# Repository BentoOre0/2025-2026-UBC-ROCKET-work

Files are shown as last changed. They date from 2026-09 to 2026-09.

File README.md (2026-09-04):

# UBC Rocket, 2025/2026

Hands-on rocketry from my first year in engineering at UBC: mechanical design and CAD,
composite manufacturing, avionics integration, and energetic (separation charge) testing.

Two projects live here. One I built with a sub-team, one I built alone in five days.

---

<table>
<tr>
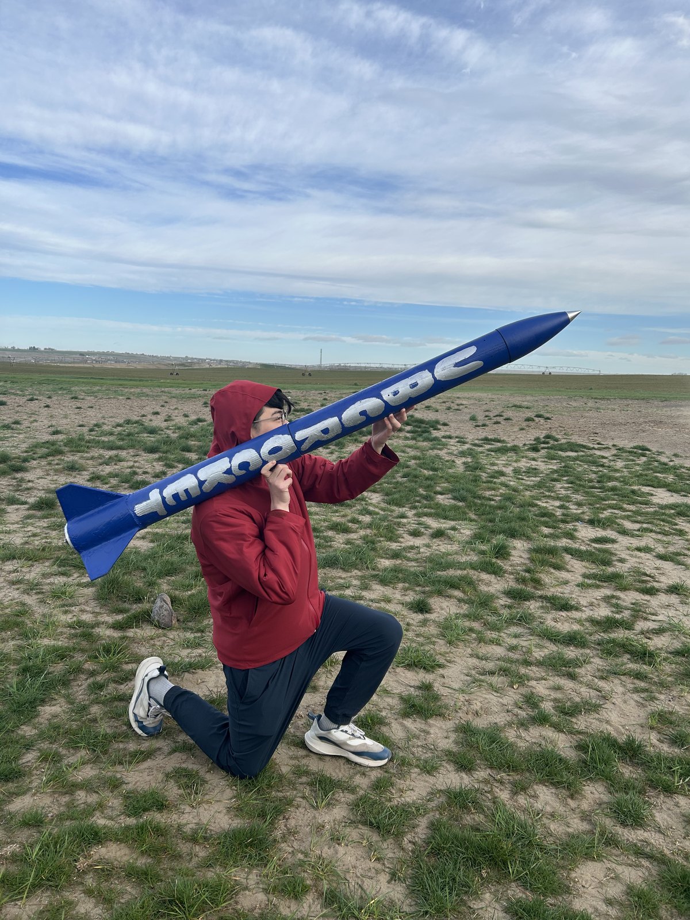
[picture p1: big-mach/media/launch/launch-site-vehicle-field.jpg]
The Big Mach at the launch site
<td width="50%"></td>
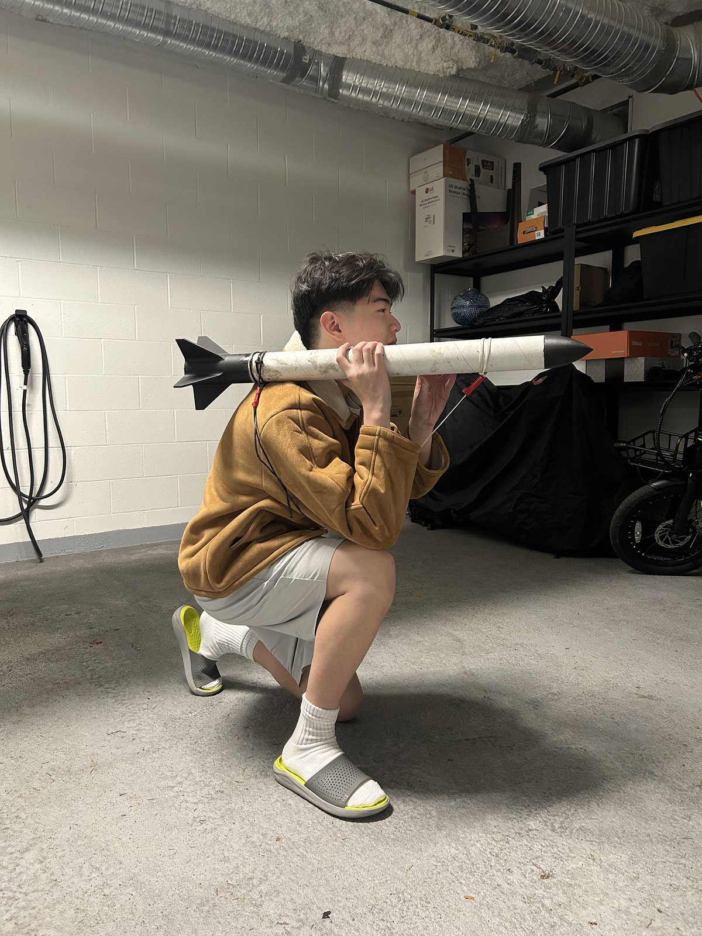
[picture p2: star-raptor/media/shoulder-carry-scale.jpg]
Star Raptor, shoulder carried for scale
<td width="50%"></td>
</tr>
<tr>
<td><h3><a href="big-mach/">The Big Mach</a></h3>
A UBC Rocket test vehicle, built so the team could fly a new reefing parachute system and an in-house avionics stack on hardware it controlled end to end.
<br><br>
<b>My role:</b> full-vehicle CAD and assembly, 3D printing, composite layup, avionics bay integration, separation charge design and ground testing.
<br><br>
<b>Scale:</b> 146 cm long, 10.7 cm diameter, 7.7 kg with motors, L935 motor, simulated Mach 1.03 and 3.06 km apogee.
</td>
<td><h3><a href="star-raptor/">Star Raptor</a></h3>
My own certification rocket, designed and built solo to earn a Canadian Association of Rocketry certification.
<br><br>
<b>My role:</b> everything. Design, CAD, printing, assembly, recovery packing. Built and flight-ready; the certification launch window was scrubbed by weather.
<br><br>
<b>Scale:</b> roughly 1 m, printed nose cone and five-fin can, motor-ejection recovery, no onboard electronics.
<br><br>
<b>CAD:</b> full SolidWorks assembly, section views, and the sliced print files, all in the repo.
</td>
</tr>
</table>

---

## What I actually did

I joined UBC Rocket as a first-year student and was put on the test-rocket sub-team.
The job of that team is to fly other people's new hardware (a reefing parachute system
and a custom avionics stack) on a vehicle we design and build ourselves. So most of my
time went into being the person who takes a requirement from another sub-team and turns
it into geometry, a printed part, a laid-up tube, or a wired-up bay.

Concretely, across the two projects:

| Area | What that meant here |
|---|---|
| **CAD** | Owned and assembled the full `FullAssembly` SolidWorks model of the Big Mach: nose cone sections, body tubes, couplers, bulkheads, centering rings, fin pattern. Modelled Star Raptor from scratch as a six-part SolidWorks assembly, then exported and sliced it myself. |
| **Simulation** | OpenRocket models for stability and trajectory, used to size the airframe and check margin before committing to a layup. |
| **Manufacturing** | 3D printing (including a PA6GF glass-filled-nylon nose cone, glass fill rather than carbon so the avionics' radio signal passes through it), fiberglass wet layups, composite fin work, paint and finishing. |
| **Avionics integration** | Physically fitting the flight computer stack, battery and charge wiring into the bay, and keeping it serviceable by the sub-team that owned it. |
| **Energetics and testing** | Sizing and massing black powder separation charges, wiring e-matches, and firing them over a remote link. |

The avionics bay component (`EDR_AVBAY_DESIGN`) came from the avionics sub-team. The
rest of the assembly and all the mating is mine. Where a claim rests on memory rather than
on something in this repository, I have said so in place rather than dressing it up.

---

## The one that shows the most

The separation charge ground test. Recovery depends on a black powder charge splitting
the airframe at the right moment, and the charge mass is not something you calculate
once and trust. You mass it out, fire it, and watch.

<table>
<tr>
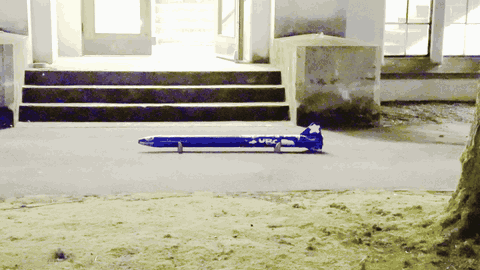
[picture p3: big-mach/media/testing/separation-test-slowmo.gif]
Separation test, slow motion
<td width="50%"></td>
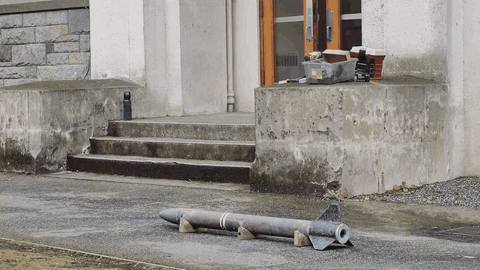
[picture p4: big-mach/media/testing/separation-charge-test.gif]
Separation charge ground test
<td width="50%"></td>
</tr>
<tr>
<td><em>Painted vehicle, filmed at 120fps and slowed roughly 3x. The sections part and stay tethered by the shock cord.</em></td>
<td><em>An earlier test on the bare airframe, real time.</em></td>
</tr>
</table>

The charge mass was found by **binary search**: bracket at 1 g and 2 g, halve the interval,
converge in three to four tests, then repeat at the winning charge to prove it was not
luck. Full detail in the
[Big Mach testing section](big-mach/README.md#separation-charge-testing).

---

## Navigation

| | |
|---|---|
| **[The Big Mach](big-mach/README.md)** | Full engineering case study: design, manufacturing, avionics, testing, launch |
| **[Star Raptor](star-raptor/README.md)** | Solo five-day build, and the scoping decisions that made it possible |
| **[Design media](big-mach/media/design/)** | OpenRocket and SolidWorks screenshots |
| **[Build media](big-mach/media/build/)** | Composite layup, printed parts, avionics bay, finished airframe |
| **[Testing media](big-mach/media/testing/)** | Separation charge ground test, charge mass measurement |
| **[Star Raptor CAD source](star-raptor/cad/)** | SolidWorks parts and assemblies, STEP exports, sliced print files |
| **[Full CAD assembly](https://github.com/BentoOre0/2025-2026-UBC-ROCKET-work/releases/tag/cad-v1)** | The complete SolidWorks assembly, 169 MB, hosted as a release asset |

```text
big-mach/
  README.md
  media/
    design/     OpenRocket + SolidWorks screenshots
    build/      composite layup, printed parts, avionics bay, finished airframe
    testing/    separation charge ground test, charge mass measurement
    launch/     launch site photos and video
star-raptor/
  README.md
  cad/          SolidWorks parts + assemblies, STEP exports, sliced print files
  media/
    cad/        SolidWorks renders and section views
    print/      build plate layouts
    ...         printed fin can, recovery packing, assembled vehicle
```

## The full CAD assembly

The complete SolidWorks assembly is 169 MB, which is too large to sit usefully in a Git
tree, so it is published as a
**[release asset](https://github.com/BentoOre0/2025-2026-UBC-ROCKET-work/releases/tag/cad-v1)**
instead. Start at `FullAssembly.SLDASM`. It needs SolidWorks to open, and the
screenshots in `big-mach/media/design/` are taken from it if you just want to look.

---

*Jeremy Aidan Yu, UBC Engineering*

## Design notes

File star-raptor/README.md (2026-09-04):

# Star Raptor

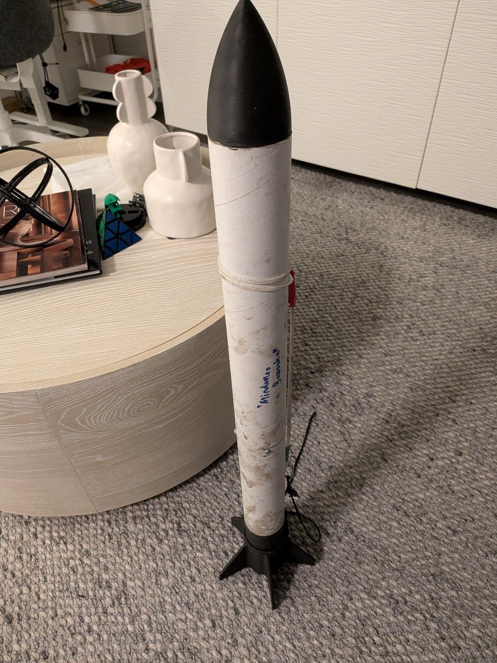
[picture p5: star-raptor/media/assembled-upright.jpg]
Star Raptor assembled


*Star Raptor, assembled and standing on its printed fin can.*

---

## What it is

Star Raptor is **my certification rocket**, a vehicle I designed and built on my own to
earn my Canadian Association of Rocketry certification. It is deliberately much simpler
than [the Big Mach](../big-mach/): no avionics, no separation charges, no composites.

It was also a **five-day build**, constrained by when the certification window fell.

That combination (solo, simple, fast) is the whole point of the project, and it is a
different kind of engineering problem from the Big Mach. On a team vehicle you can
specialise. Here every decision was mine and every decision had to be one I could
actually execute alone, at home, inside a week.

Star Raptor carried on the shoulder for scale

*Star Raptor off the stand. Roughly a metre of airframe: printed nose cone, cardboard
body tube, printed five-fin can, with the kevlar shock cord and its anchor visible at
the shoulder.*

---

## The constraint that shaped it

The design rule I set was: **it has to be buildable at home from printed parts and
hardware-store components, with no electronics.**

That single constraint decides most of the vehicle:

| Decision | Why |
|---|---|
| **Motor-ejection recovery, no flight computer** | The propellant grain has an ejection charge built in. If I let the motor deploy the parachute, I need no altimeter, no battery, no e-matches, no charge wells, and nothing to debug in five days. |
| **3D-printed nose cone and fin can** | The two geometrically fussy parts. Printing them meant I could iterate the fin design without tooling, and a printed fin can guarantees fin alignment far better than I could hand-align individual fins on a tube. |
| **Cardboard body tube** | Adequate for the altitude and velocity involved, and available immediately. Composite work would have cost days I didn't have. |
| **U-bolts, kevlar shock cord, off-the-shelf parachute** | Home Depot and hobby-shop parts. Recovery hardware is the one place not to improvise, and buying it removed a whole category of risk. |

The engineering content here is in the **scoping**, not the sophistication. Choosing a
recovery architecture with no failure modes I'd have to test was the decision that made
a five-day build possible.

---

## Design

I modelled the whole vehicle in SolidWorks as an assembly (`MyRocketAssem`) before
printing anything. For a five-day build that is not ceremony, it is the only way to find
out that two parts do not fit while the fix still costs a re-export instead of a reprint.

<table>
<tr>
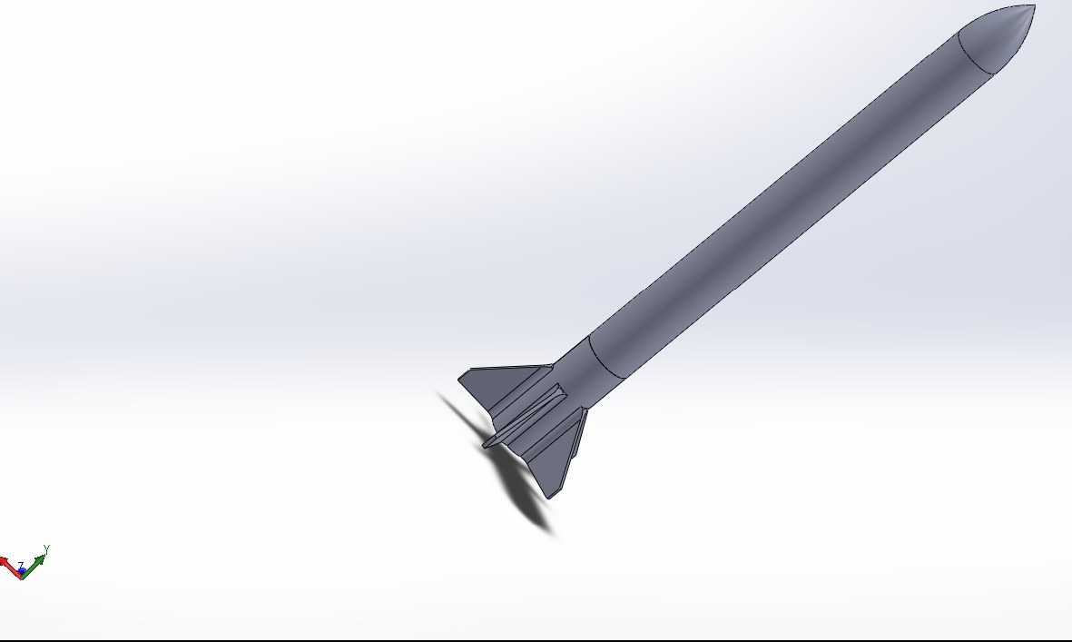
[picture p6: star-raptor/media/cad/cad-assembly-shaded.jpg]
Star Raptor full assembly in SolidWorks
<td width="55%"></td>
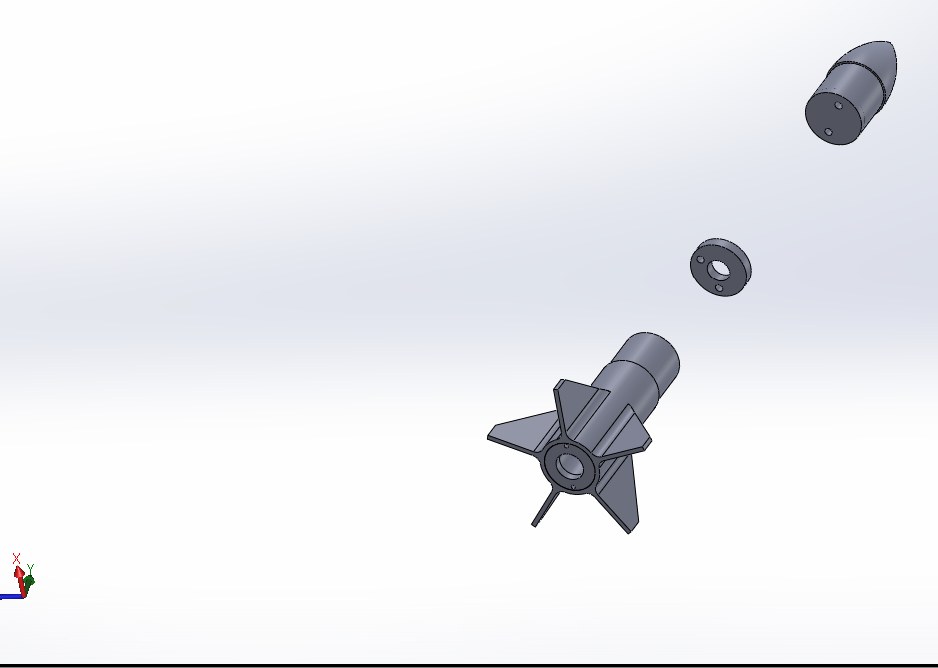
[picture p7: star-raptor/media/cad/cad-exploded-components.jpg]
Exploded view of the printed components
<td width="45%"></td>
</tr>
<tr>
<td><em>The full assembly. Nose cone, body tube, and the printed fin can.</em></td>
<td><em>The same assembly exploded, which is the view that matters for a printed rocket:
nose cone at the top, the ring that anchors the U-bolt below it, and the fin can at the
bottom. These are the parts that have to mate on the first try.</em></td>
</tr>
</table>

The assembly is six parts:

| Part | File |
|---|---|
| Nose cone | `nosecone.SLDPRT` |
| Body tube | `LowerBodyTube.SLDPRT` |
| Fin can, five fins in one piece | `FinCan.SLDPRT` |
| End cap | `endcap.SLDPRT` |
| U-bolt attachment, body tube end | `uboltattatchmentpart.SLDPRT` |
| U-bolt attachment, nose cone end | `Uboltattatchmentpartnosecone.SLDPRT` |

**Five fins was a cosmetic decision.** Three or four fins would have done the job on a
vehicle this size; I went with five because I liked how it looked. The rule I held myself
to was that the styling choice had to survive the stability check rather than drive it,
and it did: extra fin area sits aft of the centre of gravity, so it pushes the centre of
pressure back and the stability margin came out fine. The cost was a little extra drag
and print time. 

### Section views

The section views are what I actually used while designing. On a printed rocket the
walls, the internal tube and the clearances between them are the design, and they are
invisible in a shaded exterior view.

<table>
<tr>
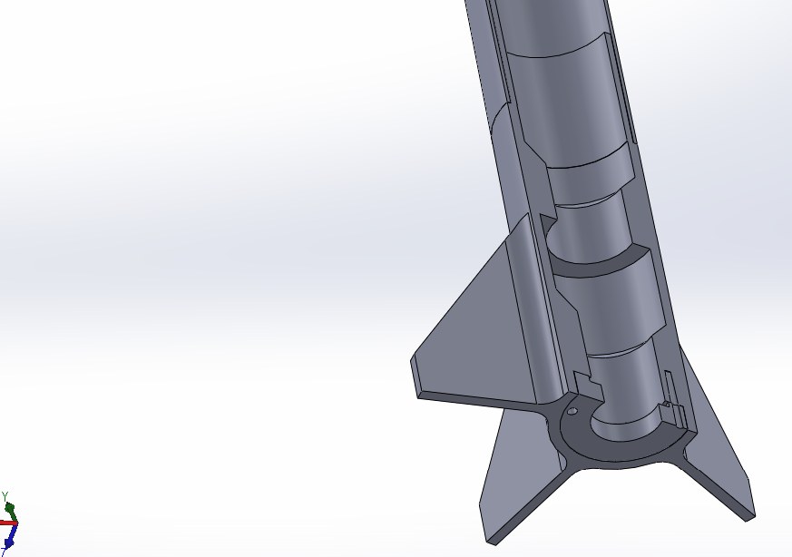
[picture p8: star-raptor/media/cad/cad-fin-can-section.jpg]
Section view through the fin can
<td width="50%"></td>
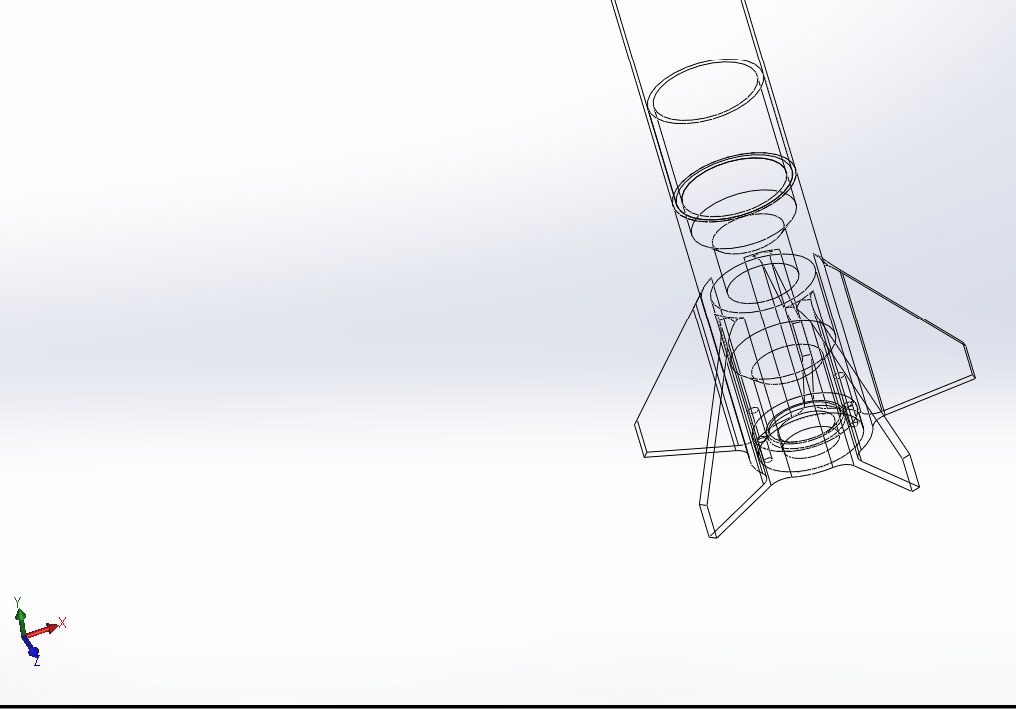
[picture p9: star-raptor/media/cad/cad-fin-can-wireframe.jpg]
Wireframe view of the fin can showing the inner tube
<td width="50%"></td>
</tr>
<tr>
<td colspan="2"><em>Left: a section cut through the aft end, showing the wall thicknesses
and the stepped joint where the fin can meets the body tube. Right: the same region in
wireframe, showing the inner tube running up inside the fin can and the rings that locate
it. Cutting the section is how you catch a wall that is too thin to print or a clearance
that closes up once the tolerances stack.</em></td>
</tr>
</table>

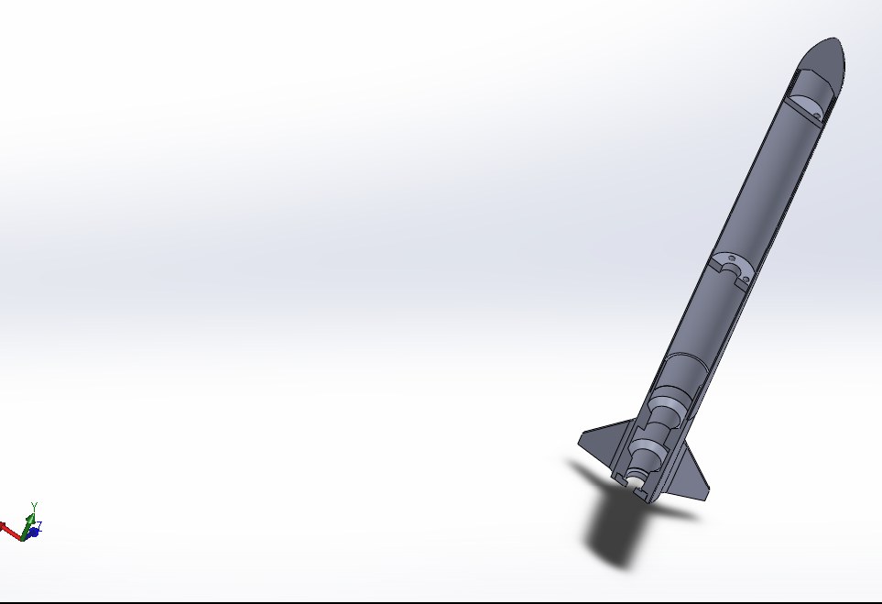
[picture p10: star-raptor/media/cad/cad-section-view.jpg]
Section view of the complete vehicle


*The full vehicle in section, showing how much of the airframe is open volume for the
recovery system.*

**The full CAD source is in [`cad/`](cad/)**: SolidWorks parts and assemblies, the STEP
exports, and the slicer project files. `MyRocketAssemFinal.SLDASM` is the assembly the
built vehicle came from.

---

## Build

### From CAD to printed part

Every printed part went the same route: model it in SolidWorks, export STEP, arrange it
on a build plate, slice, print. The sliced project files are in
[`cad/toprint/`](cad/toprint/) and [`cad/final print top parts/`](cad/final%20print%20top%20parts/),
so the print setup is recoverable rather than just described.

<table>
<tr>
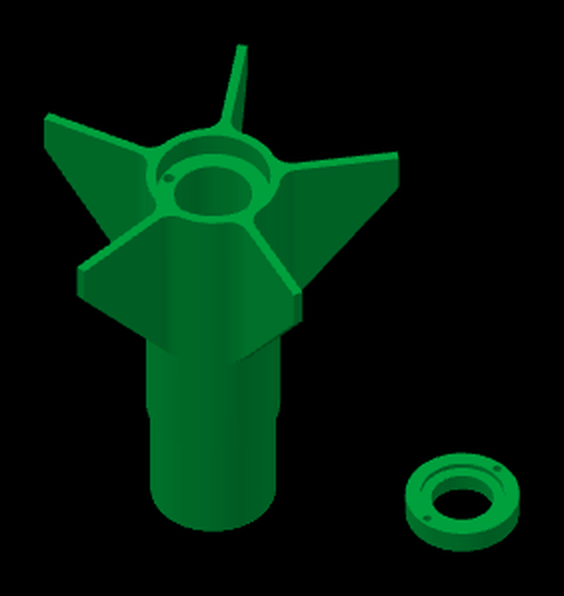
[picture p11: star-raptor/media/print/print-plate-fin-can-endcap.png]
Build plate with the fin can and end cap
<td width="50%"></td>
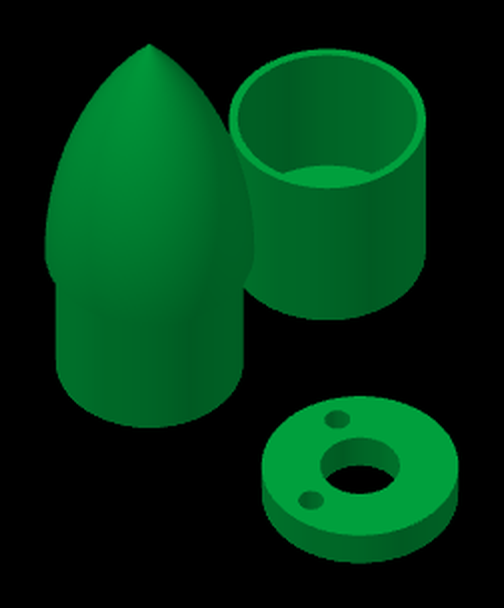
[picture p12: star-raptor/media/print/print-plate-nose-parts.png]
Build plate with the nose cone and U-bolt attachment parts
<td width="50%"></td>
</tr>
<tr>
<td><em>Fin can and end cap on one plate. The fin can prints standing on its aft face, so
the fins are supported by the plate rather than cantilevered in mid-air.</em></td>
<td><em>The upper parts on another plate: nose cone, the body tube U-bolt attachment, and
the nose cone U-bolt attachment.</em></td>
</tr>
</table>

Everything was printed with a **0.6 mm nozzle at 0.30 mm layer height**. That is a coarse
setting, and it was deliberate: a bigger nozzle and thicker layers cut print time hard,
and on structural parts the thicker extrusion is stronger across layer lines than a fine
one. Surface finish was the thing I could afford to give up. Print time was not.

### The physical parts

<table>
<tr>
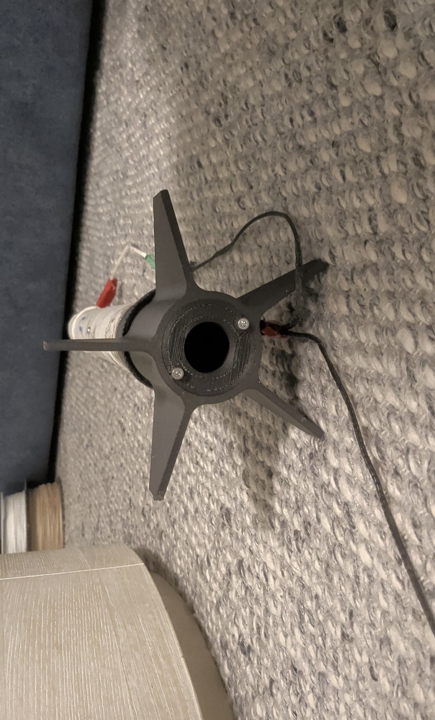
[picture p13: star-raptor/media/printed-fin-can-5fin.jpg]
Printed five-fin can, aft view
<td width="50%"></td>
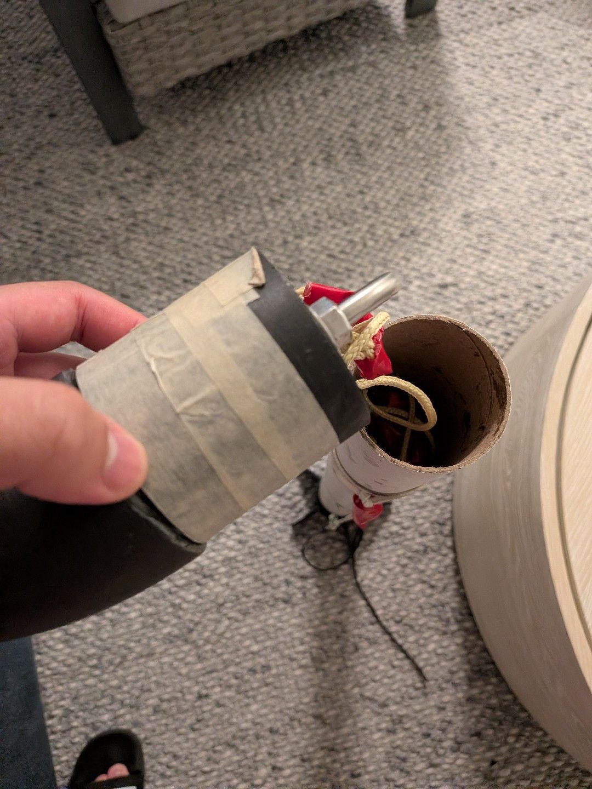
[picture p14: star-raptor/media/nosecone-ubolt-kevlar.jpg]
Nose cone with U-bolt and kevlar shock cord
<td width="50%"></td>
</tr>
<tr>
<td colspan="2"><em>Left: the printed fin can, viewed from the aft end down the motor tube. Printing the fin can as a single part fixes the fin alignment in the model instead of during assembly, and it is what made a five-fin can (a look I chose, not a requirement) no harder to build than a three-fin one. Right: the nose cone's recovery attachment, a through-bolt anchoring the kevlar shock cord. This joint takes the full deployment shock, so it is bolted through the structure rather than glued.</em></td>
</tr>
</table>

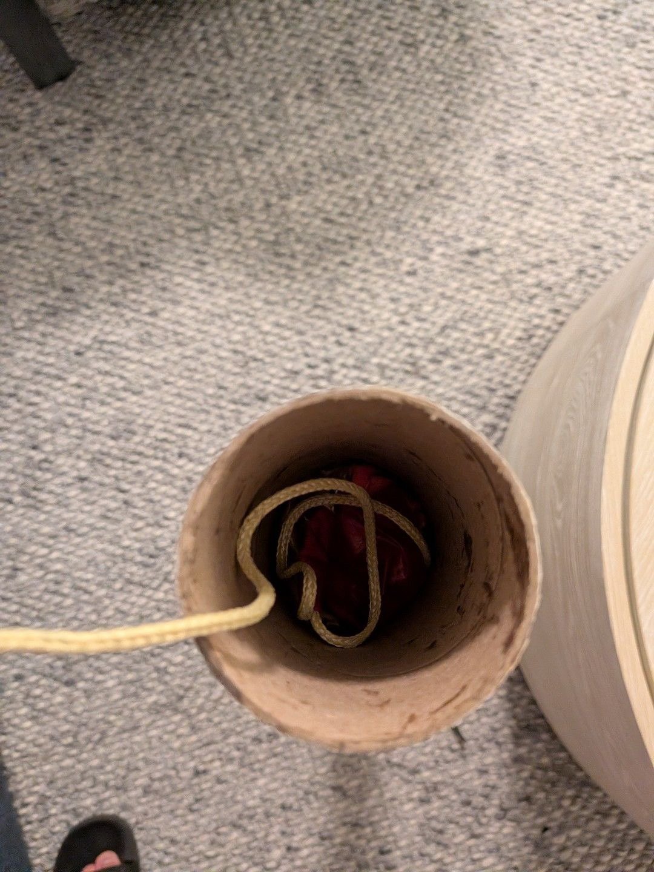
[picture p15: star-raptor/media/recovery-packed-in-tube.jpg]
Recovery packed in the airframe


*Looking down the body tube at the packed recovery system: kevlar shock cord running
down to the anchor, parachute packed above it. The motor's ejection charge pressurises
this volume to push the nose cone and parachute out.*

---

## My role

All of it. Design, CAD, printing, assembly, and recovery packing. No sub-teams, no
inherited hardware. The certification launch window was scrubbed by weather, so the
vehicle in these photos is built and flight-ready but has not flown.

---

## What I took away from it

**Model the whole thing before printing any of it.** The parts that had to mate (fin can
to body tube, nose cone to its U-bolt ring) were the parts most likely to waste a print,
and a full assembly with section views is where you find a wall that is too thin or a
clearance that has closed up. A reprint of the fin can costs hours I did not have. A
re-export costs minutes. Building the assembly first was what kept the five days
realistic.

**print a jig next time.** If I need to drill holes in a circular pattern around a tube 3D print a jig to help with that.

**This was the transition project.** Before this, most of my work was software and
algorithmic. Star Raptor was the first thing I took from a blank SolidWorks assembly to a
finished physical vehicle on my own. Getting an object through that whole loop, including
the parts that are just tedious, is what made the hardware work that followed possible: the Big Mach, and
[the quadruped](https://github.com/BentoOre0/Modded-Nova-SM3).

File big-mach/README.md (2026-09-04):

# The Big Mach

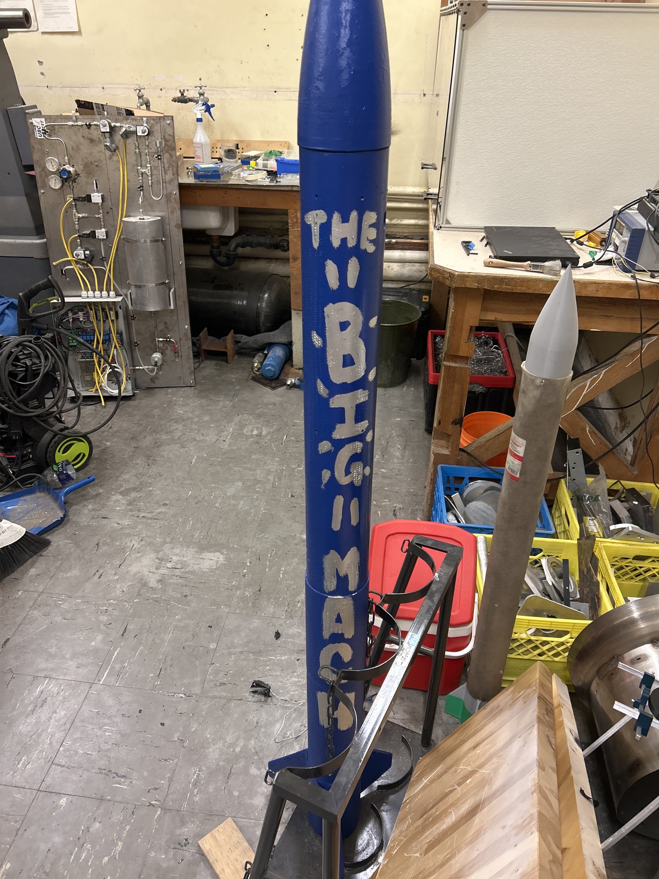
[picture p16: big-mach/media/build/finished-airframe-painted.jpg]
The finished airframe, painted and named


*The Big Mach at the end of the build, in the UBC Rocket workshop. The bare grey
PA6GF nose cone on the right is a spare print of the same part.*

---

## What it is

The Big Mach is a UBC Rocket **test vehicle**. It exists so that two pieces of new
hardware, a reefing parachute recovery system and an in-house avionics stack, could be
flown and characterised on something the team controlled end to end, rather than risking
them on the competition rocket.

That framing drives every design decision on the vehicle. It has to fly high and fast
enough to be a meaningful test, it has to separate reliably to give the recovery system
a chance to work, and the avionics bay has to be accessible enough that another sub-team
can service their own hardware inside it.

From the OpenRocket model (`FINAL_L935_BIG_MACH_with_centering rings.ork`):

| Parameter | Value |
|---|---|
| Length | 146 cm |
| Max diameter | 10.7 cm |
| Mass, no motors | 5176 g |
| Mass, with motors | 7718 g |
| Motor configuration | `3147L935-P` (L-class, 935 N average) |
| Stability margin | 1.5 cal (11%), CG 79.2 cm / CP 95.3 cm |
| Simulated apogee | 3064 m |
| Simulated max velocity | 347 m/s, **Mach 1.028** |
| Simulated max acceleration | 195 m/s² |

The name is not decoration: the simulation puts the vehicle just over Mach 1, which is
what the airframe and fin design had to survive.

<table>
<tr>
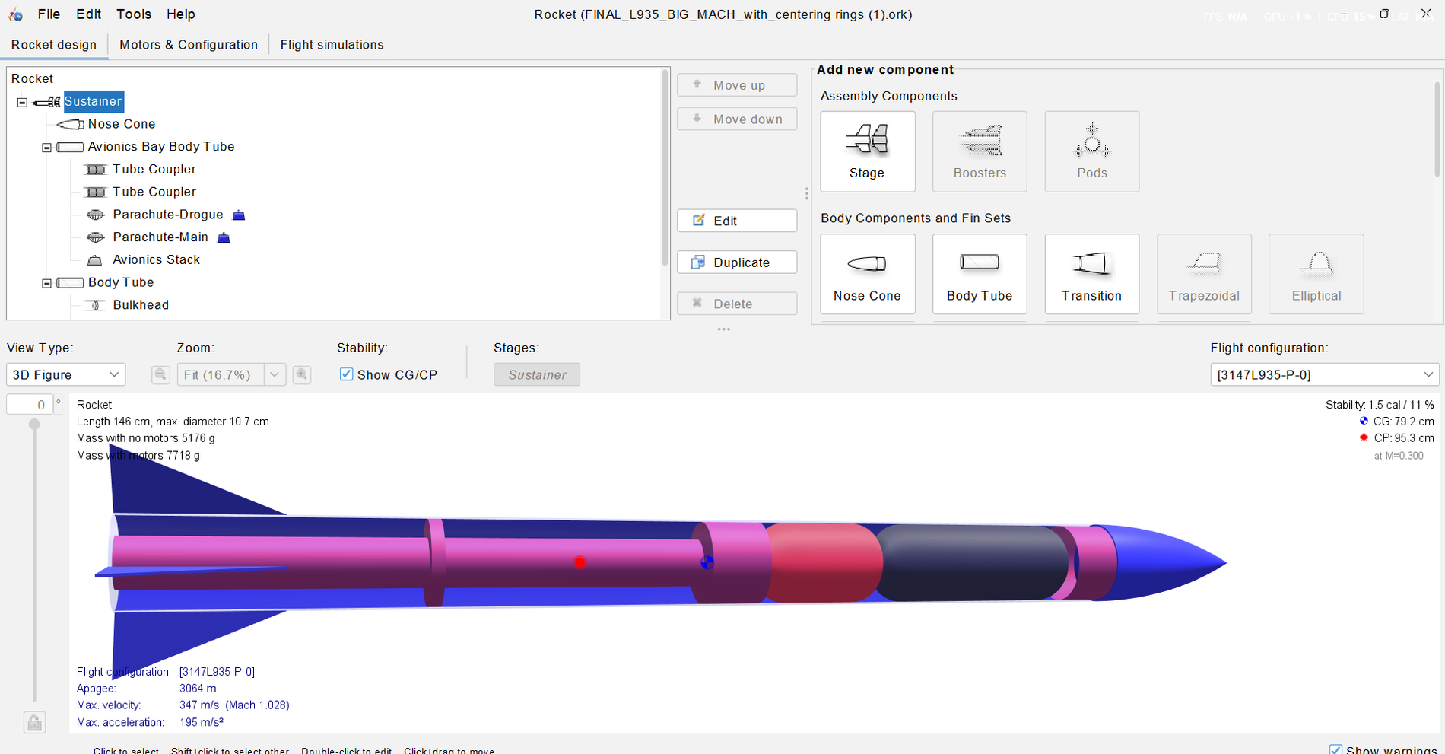
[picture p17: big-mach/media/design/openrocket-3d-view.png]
OpenRocket 3D view
<td width="50%"></td>
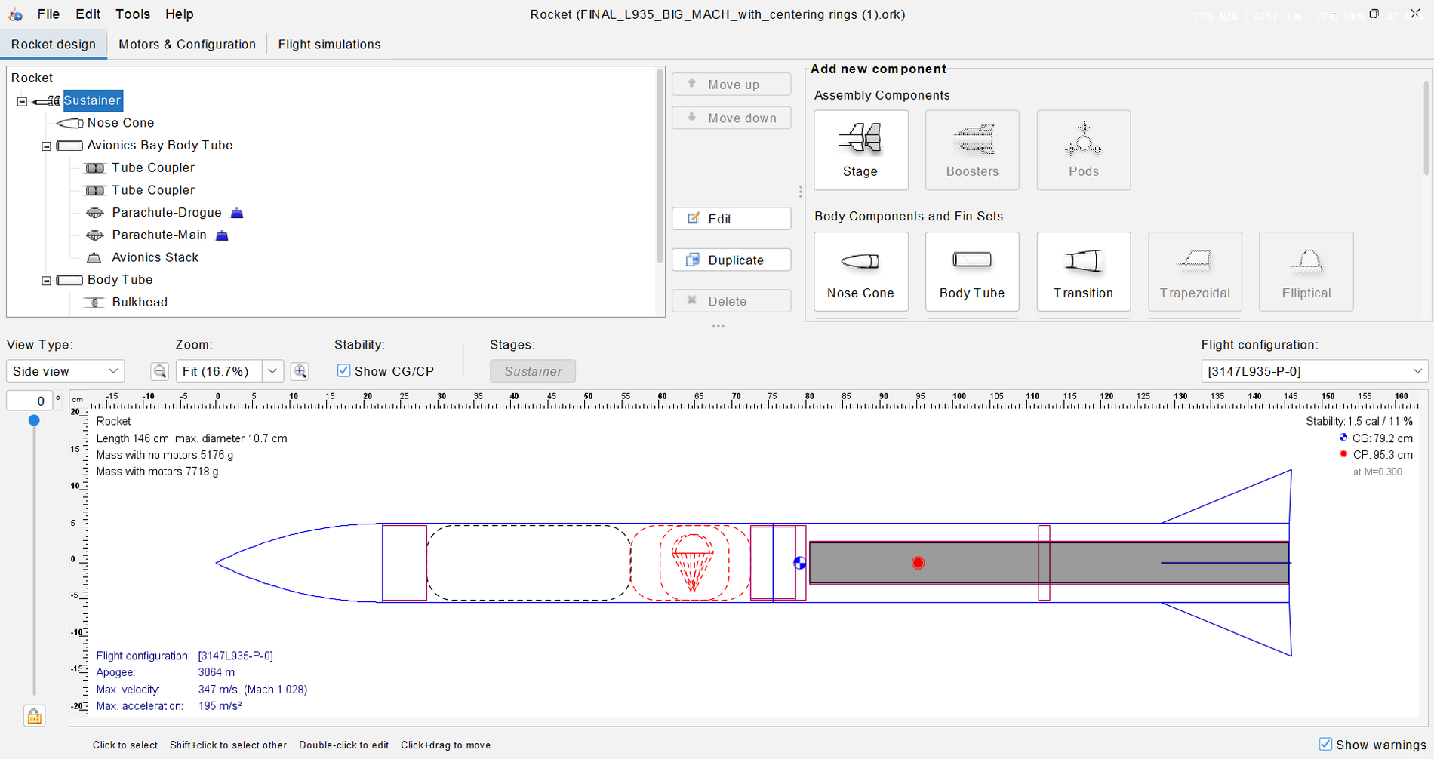
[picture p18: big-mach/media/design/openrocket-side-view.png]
OpenRocket side view with CG and CP marked
<td width="50%"></td>
</tr>
<tr>
<td colspan="2"><em>OpenRocket model. The side view shows the internal stack (nose cone, avionics bay with drogue and main parachutes either side of the avionics stack, coupler, then the motor body tube) and the CG/CP markers used to check the stability margin.</em></td>
</tr>
</table>

---

## My role

I was one of three people on the test-rocket sub-team. The sub-team designed and built
the vehicle; the recovery, avionics, embedded software and composites sub-teams supplied
the payload hardware and the expertise. A lot of the job was translation: taking a
requirement from another sub-team and turning it into something that could actually be
printed, laid up, or bolted in.

**What was mine:**

- **The full-vehicle SolidWorks assembly.** I built and mated `FullAssembly`: nose cone
  sections (`NoseconeTip`/`NoseConeMiddle`/`NoseconeBottom`), avionics bay body tube,
  motor body tube, inner tube, bulkheads, centering rings, the fin pattern
  (`LocalCirPattern1`) and the bottom plate.
- **OpenRocket modelling** for stability and trajectory.
- **3D printing.** The majority of the sub-team's printed prototypes and flight parts
  went through me, including the PA6GF (glass-filled nylon) nose cone, printed in the
  glass-filled rather than the carbon-filled grade so the avionics could still get a
  radio signal through it.
- **Fiberglass wet layup** for the custom body tubes.
- **Avionics bay integration.** Fitting the flight computer stack, battery and charge
  wiring into the bay.
- **Separation charge design and ground testing.** Sizing and massing black powder
  charges, wiring e-matches, and firing them over a remote link.
- **Painting and finishing.**

**What was not mine:**

- The **avionics bay internal design** (`EDR_AVBAY_DESIGN` in the assembly tree) came
  from the avionics sub-team. I integrated it and built the structure around it. I did
  not design the flight computer or its sled.
- The **reefing parachute system** is the recovery sub-team's design. The Big Mach was
  the vehicle that carried it.
- The **composite layups and fin fabrication were done with the team.** I did the work
  alongside more experienced members, not alone. The photo captions in `media/build/`
  reflect this distinction as I recorded it at the time.

---

## Design

<table>
<tr>
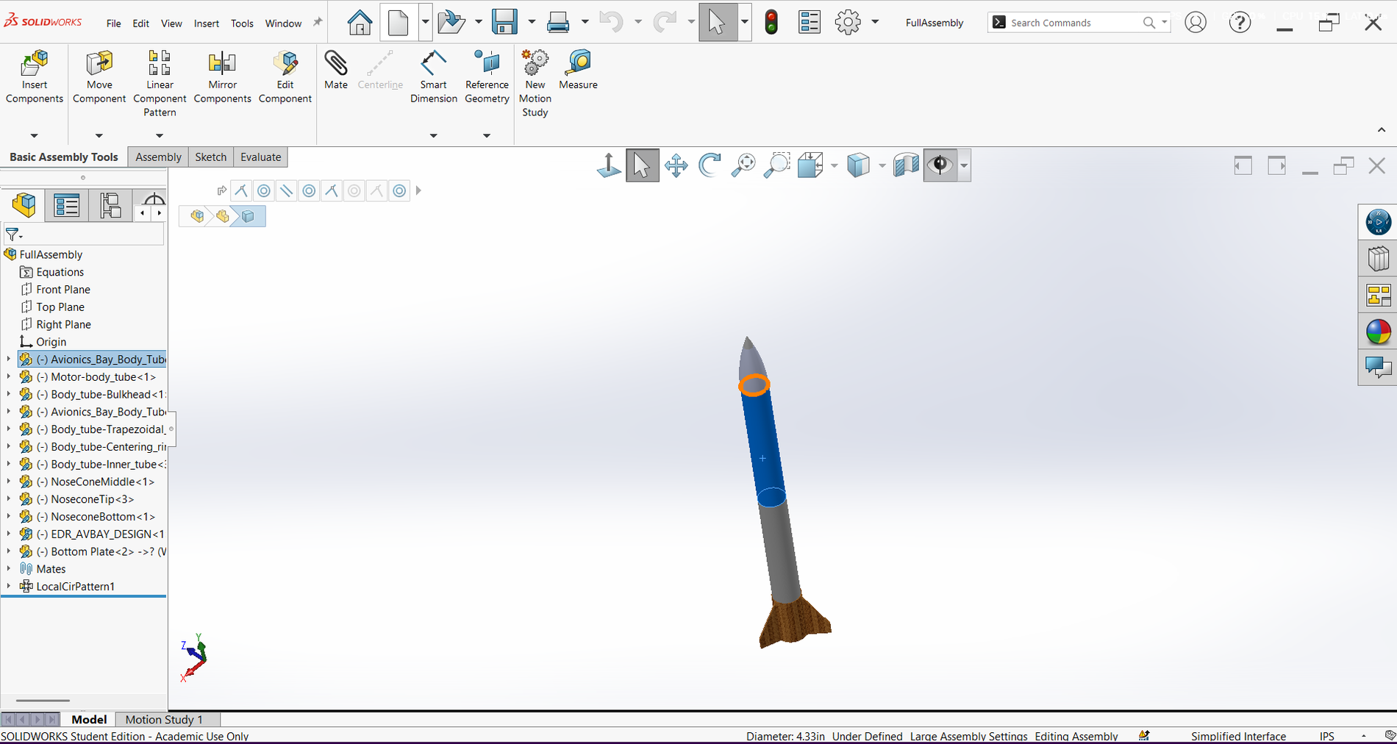
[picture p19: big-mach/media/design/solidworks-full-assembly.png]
SolidWorks full assembly
<td width="50%"></td>
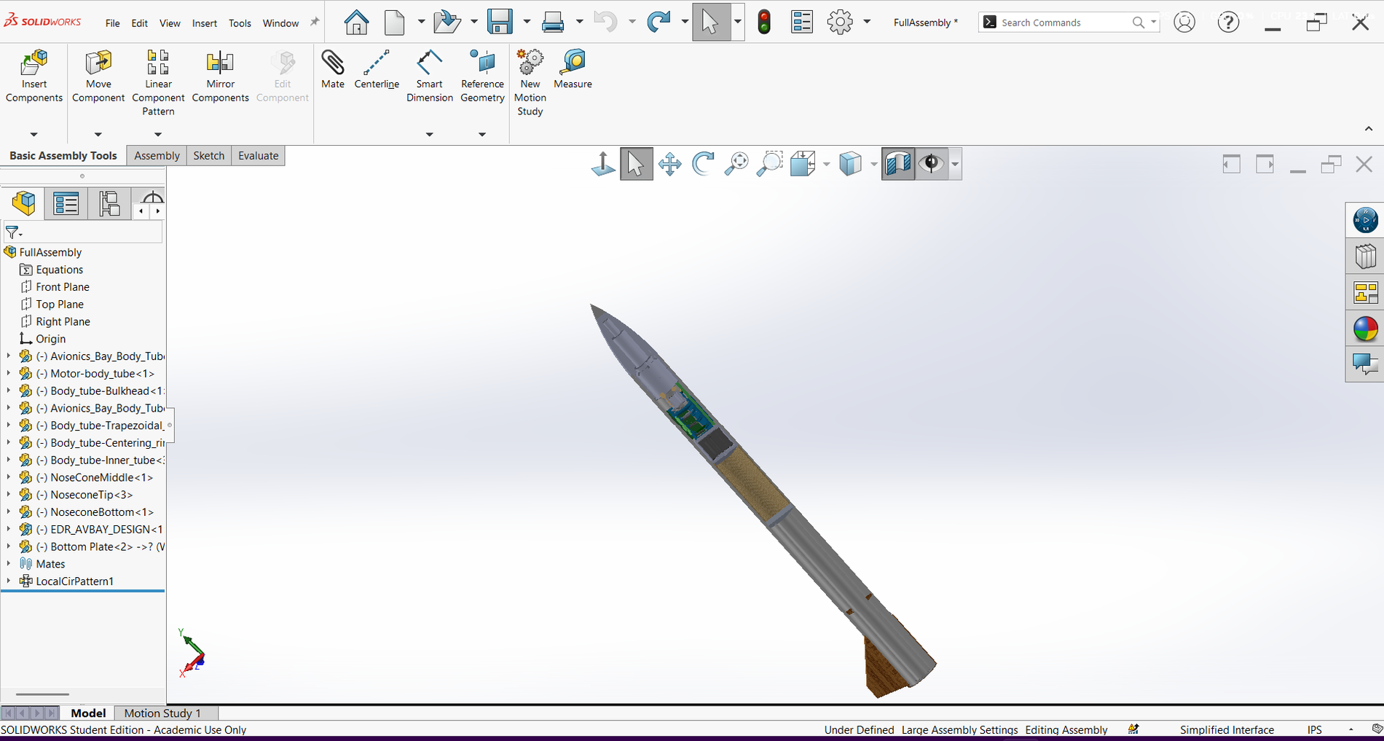
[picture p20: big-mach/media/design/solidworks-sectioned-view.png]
SolidWorks sectioned view showing internal avionics
<td width="50%"></td>
</tr>
<tr>
<td colspan="2"><em>Left: the assembled vehicle in SolidWorks, with the component tree showing the parts I mated. Right: the same model sectioned, exposing the avionics stack inside the bay. This is the view that mattered when checking that the avionics sub-team's hardware and the recovery hardware could physically coexist in one bay.</em></td>
</tr>
</table>

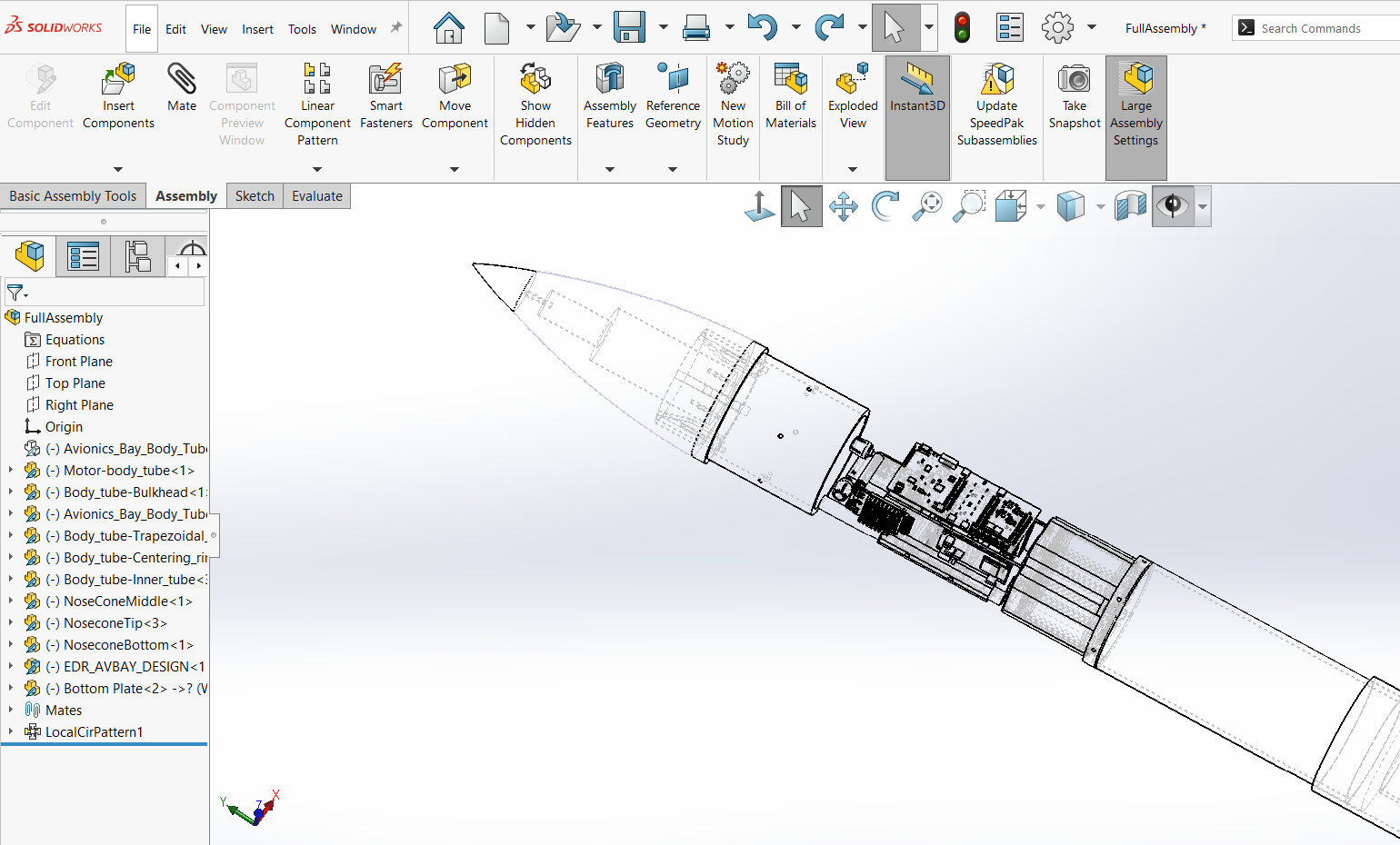
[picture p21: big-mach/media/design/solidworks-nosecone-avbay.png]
Nose cone and avionics bay detail


*Nose cone and avionics bay, hidden-line view. The avionics bay is the shoulder section
behind the cone; the recovery hardware packs either side of the electronics.*

> **Full assembly available.** The complete SolidWorks assembly (37 files, 205 MB
> uncompressed) is published as a
> [release asset](https://github.com/BentoOre0/2025-2026-UBC-ROCKET-work/releases/tag/cad-v1).
> Start at `FullAssembly.SLDASM`. The avionics bay, backplane, connector and pyro board
> assemblies inside it belong to the avionics sub-team; the airframe and the top-level
> mating are mine.

---

## Manufacturing

<table>
<tr>
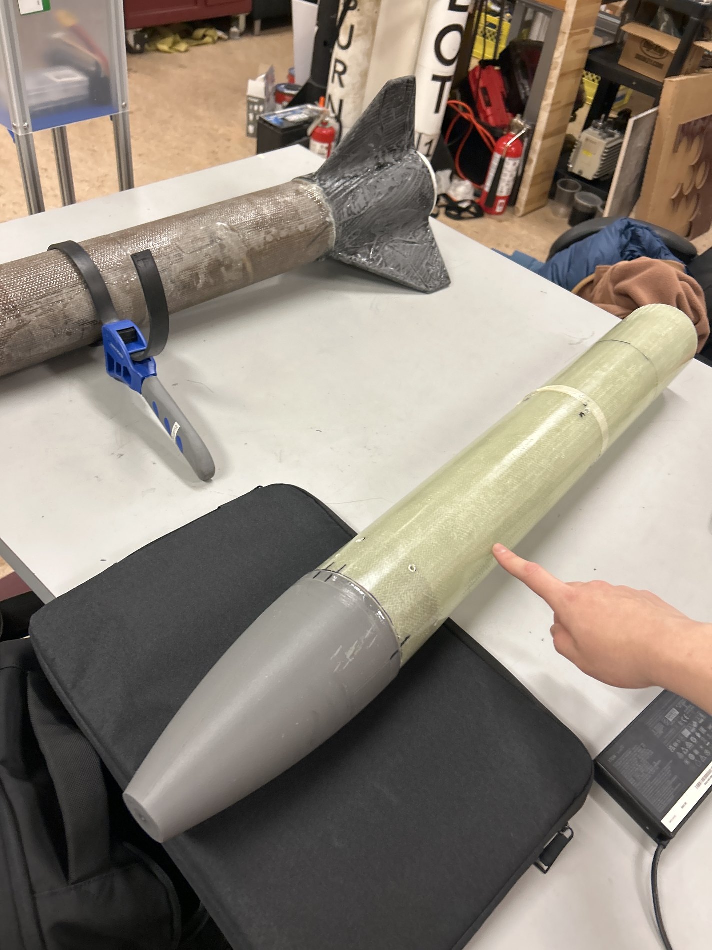
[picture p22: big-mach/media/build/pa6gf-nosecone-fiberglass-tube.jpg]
PA6GF printed nose cone next to fiberglass body tube
<td width="50%"></td>
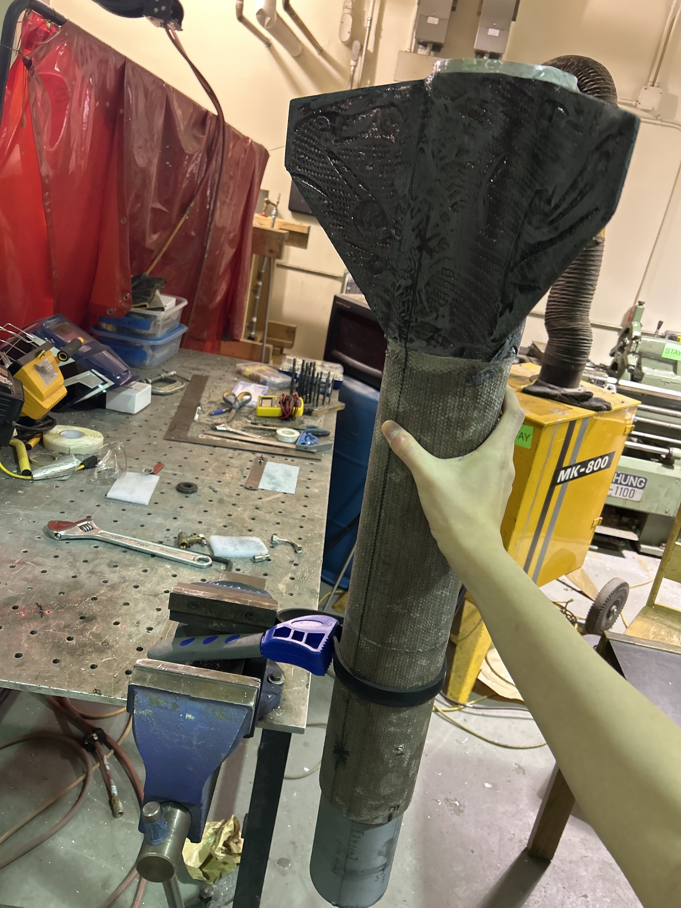
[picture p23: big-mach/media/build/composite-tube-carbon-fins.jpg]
Composite body tube and carbon fibre fin
<td width="50%"></td>
</tr>
<tr>
<td colspan="2"><em>Left: the PA6GF nose cone I printed, next to the green fiberglass body tube. PA6GF (glass-filled nylon) was chosen over PA6CF, the carbon-filled version of the same nylon, because glass fill is transparent to radio waves and carbon fill is not. The nose cone sits over the avionics, so anything the flight computer transmits or receives has to pass through that wall. PA6CF would have given similar mechanical performance and shielded the radios. Glass fill keeps the stiffness and temperature capability the cone needs, since it sees the highest aerodynamic heating and stagnation pressure on the vehicle, without blocking the signal. Right: the composite airframe and a carbon fibre fin during fin fabrication: fiberglass and phenolic in the tube, carbon in the fins.</em></td>
</tr>
</table>

<table>
<tr>
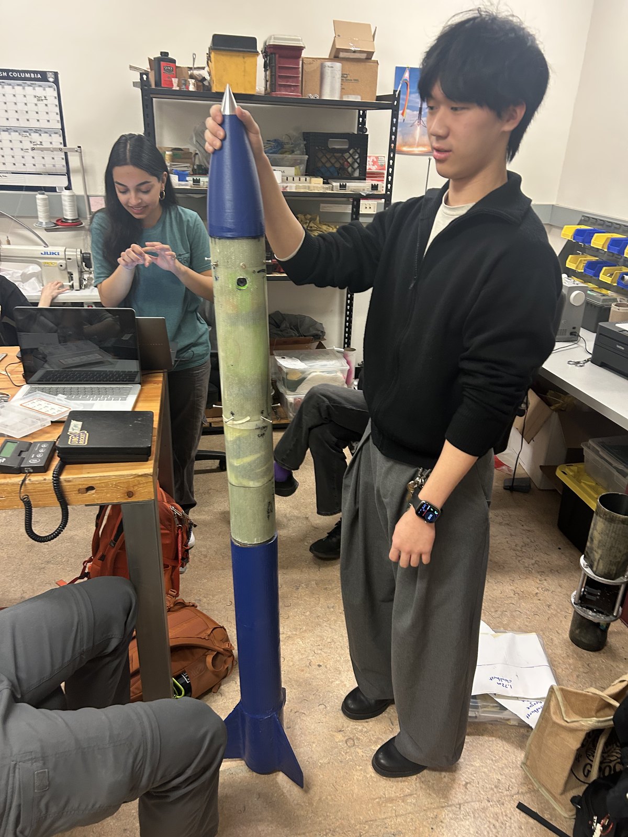
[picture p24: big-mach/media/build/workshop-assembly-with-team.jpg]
Assembling the airframe in the workshop
<td width="33%"></td>
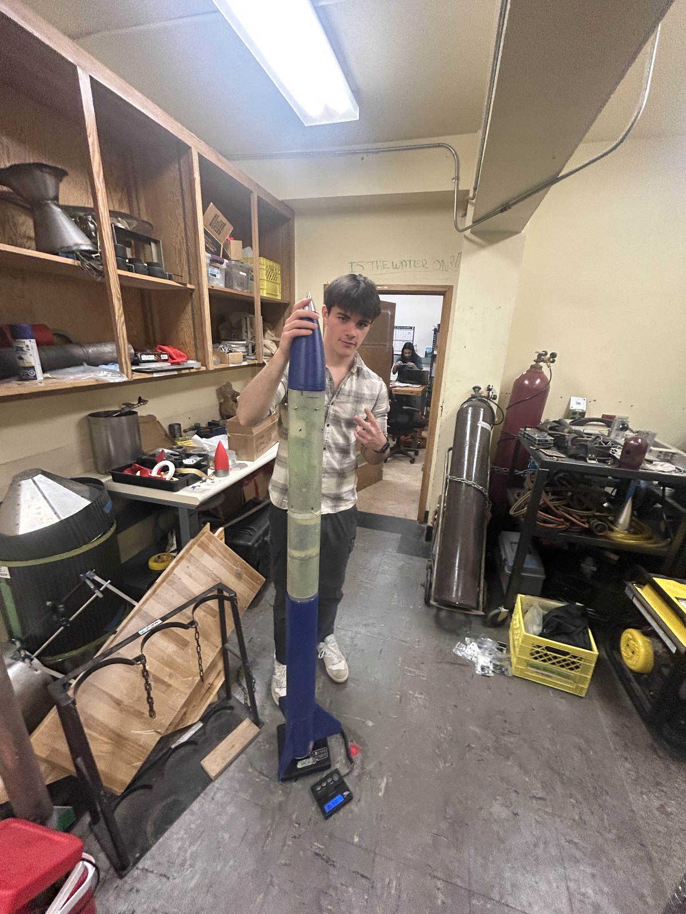
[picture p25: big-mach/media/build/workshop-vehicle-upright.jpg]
Vehicle standing in the workshop
<td width="33%"></td>
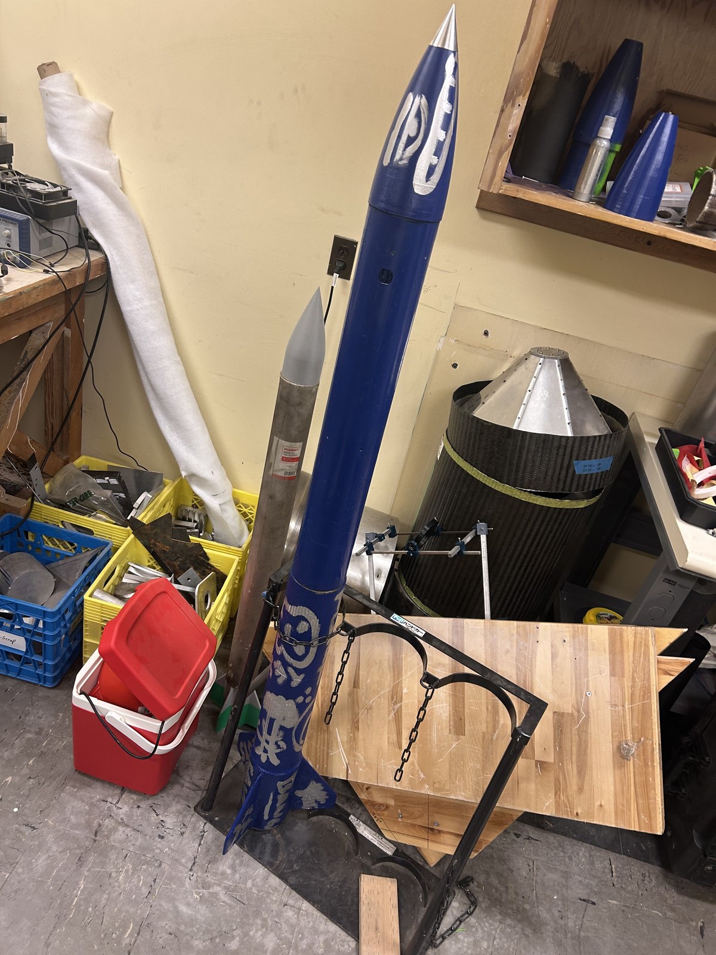
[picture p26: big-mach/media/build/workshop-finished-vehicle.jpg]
Finished vehicle in the workshop
<td width="33%"></td>
</tr>
<tr>
<td colspan="3"><em>Build progress in the UBC Rocket workshop. Left: airframe going together, with the bare composite section still unpainted. Middle and right: the vehicle standing complete, alongside the team's other airframes and nose cones.</em></td>
</tr>
</table>

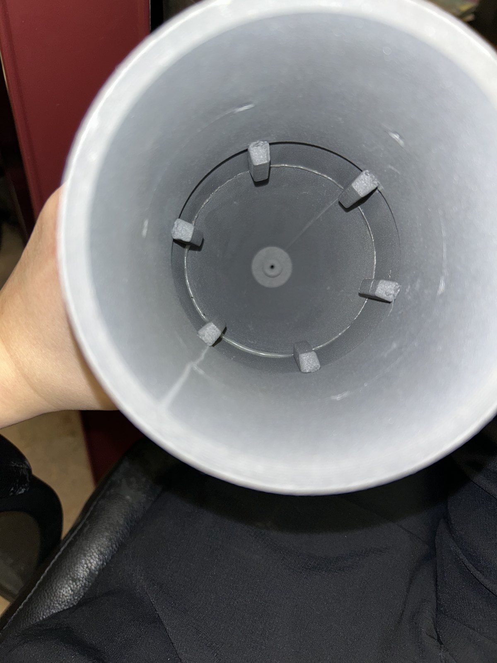
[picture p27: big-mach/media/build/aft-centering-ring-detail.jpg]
Aft end of the airframe, looking down the body tube


*Looking down the airframe at the motor tube, held concentric inside the body tube by a
centering ring, with printed blocks spaced around the annulus.*

### The layup diameter mismatch

The most instructive manufacturing problem on this project was a **diameter mismatch on
the first fiberglass wet layup**. The tube we produced did not come out at a diameter
that mated correctly with the parts it had to meet, so the layup had to be reworked and
re-run rather than salvaged.

The lesson that actually stuck is that on a wet layup the mandrel is not the only thing
setting the finished diameter. Layer count, resin uptake and how hard the tube is
compacted all stack into the final wall thickness, and a coupler fit that is toleranced
tightly on paper has very little room to absorb that. The fix was to treat the layup
schedule as something to be designed against a target *finished* inside diameter and
verified, rather than assumed from the mandrel.

> **Evidence note.** I have no photograph of the mismatched tube itself, and no written
> record of the measured error. This section is from memory. The composite work that is
> documented here is the successful second attempt and the fin fabrication.

---

## Fin flutter analysis

A fin that flutters shakes itself apart. The fins had to survive a vehicle that the
simulation puts just over Mach 1, so before committing to the fin design I needed to know
the speed at which bending-torsion flutter would start, and confirm the vehicle never
reaches it.

I used the flutter criterion from **NACA TN 4197 (Equation 18)**, the standard closed-form
prediction for low aspect ratio solid fins tapered toward the tip:

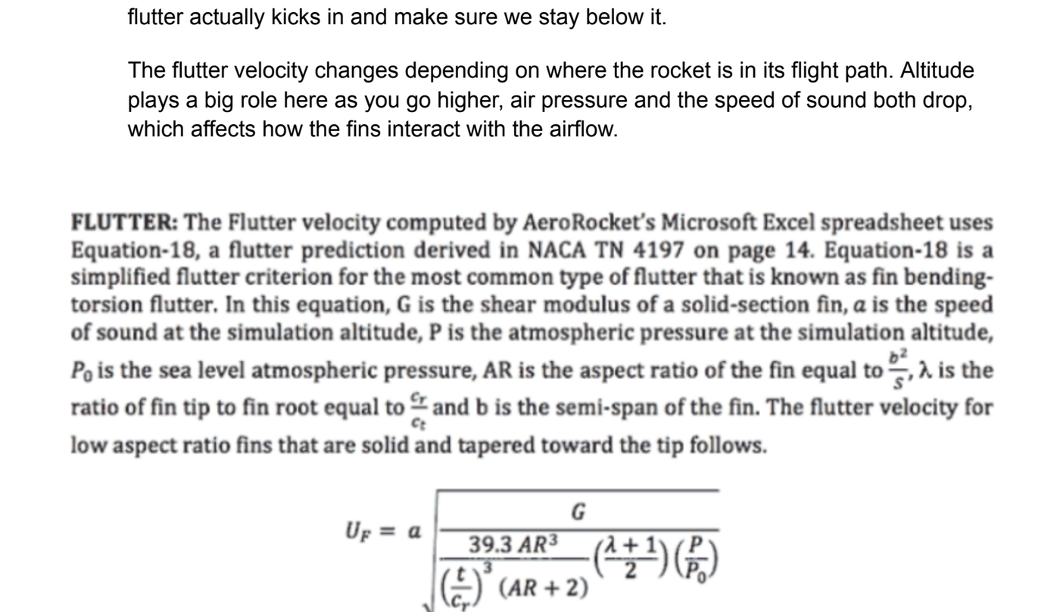
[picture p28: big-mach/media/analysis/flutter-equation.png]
Flutter velocity equation, NACA TN 4197 Equation 18


`a` is the speed of sound at altitude, `G` the shear modulus of the fin, `AR` the aspect
ratio, `λ` the tip-to-root chord ratio, `t/c_r` the thickness ratio, and `P/P0` the
pressure ratio against sea level. Because `a` and `P` both fall with altitude, flutter
speed is not a single number: it has to be evaluated along the whole trajectory. I pulled
altitude, local speed of sound and vehicle Mach number from the OpenRocket simulation and
evaluated the criterion at each point.

Trapezoidal fin set configuration in OpenRocket

*The fin set as defined in OpenRocket, and the parameters the flutter criterion consumes.
These are the numbers that go into the equation above.*

Fin geometry, taken from the CAD model and the OpenRocket trapezoidal fin set:

| Parameter | Value |
|---|---|
| Number of fins | 3 |
| Root chord | 8 in |
| Tip chord | 2 in |
| Semi-span (height) | 4.32 in |
| Sweep length / angle | 5 in / 49.2 deg |
| Thickness | 0.25 in, rounded cross section |
| Fin cant | 0 deg |
| Material | PLA, 100% infill (1.25 g/cm^3) |
| Fin set mass | 329 g |

**Result: flutter velocity runs about Mach 2.5 at sea level to Mach 2.9 at 2500 m, while
the vehicle peaks just under Mach 1.0 at roughly 500 m.**

<table>
<tr>
<td width="50%">Flutter velocity against altitude</td>
<td width="50%">Flutter velocity against vehicle velocity</td>
</tr>
<tr>
<td><em>Flutter velocity rising with altitude, Mach 2.5 to 2.9.</em></td>
<td><em>The one that matters: flutter velocity (blue) against actual vehicle velocity (red) over the whole flight. The gap between the curves is the margin.</em></td>
</tr>
</table>

The right-hand plot is the whole point of the exercise. The red curve is the vehicle,
peaking just under Mach 1.0 early in the burn and bleeding off; the blue curve is the
speed at which the fins would start to flutter. They never come close to touching, so the
fin design was cleared on that basis.

> **Where this analysis is weak.** The shear modulus is the input the whole result hinges
> on, and I did not have a measured value for our actual fin material. I used a value
> assumed from fins I believed had similar properties, which I flagged in the team
> documentation at the time as the soft spot in the calculation. The honest way to close
> it is a deflection test on a real fin: apply a known force at the tip, measure the
> deflection, back out `G`. The margin here is large enough (roughly 2.5x) that a
> substantial error in `G` would not change the conclusion, which is the only reason the
> assumption was acceptable.

The flutter working, the fin dimensions and the resulting plots are in
[`fin-flutter-and-separation-testing-extract.pdf`](docs/fin-flutter-and-separation-testing-extract.pdf).

That document is a **collaborative team document** that I contributed to, not something I
wrote alone, and it is published here as an extract. The fin flutter analysis is the part
I can point to as my own work. Elsewhere in it I contributed without being able to draw a
clean line around which paragraphs are mine, so I am not going to claim the document
wholesale. The pages covering the black powder packing procedure are explicitly credited
to another sub-team and are left out entirely, along with the operational pages carrying
hardware credentials.

---

## Avionics integration

Avionics bay stack

*The avionics bay stack out of the airframe: the flight computer boards on their printed
sled, screw-terminal blocks for the charge wiring, power leads and connectors, and the
battery strapped below. My work here was the physical integration: getting this stack,
its battery and its charge wiring to fit, mount and route inside the bay, and remain
serviceable by the avionics sub-team.*

LiPo battery wired to the Eggtimer board

*Power and firing hardware on the bench before it went into the bay: a 2S LiPo (3250 mAh,
7.4 V, 24 Wh) on an XT60 lead, wired through to the Eggtimer board with its WiFi module
visible. The Eggtimer needs 2S/7.4 V, so the pack choice is set by the board. This is the
link between the battery and the e-match that fires the separation charge, and it is the
part of the electronics I was responsible for physically integrating.*

---

## Separation charge testing

Recovery on this vehicle depends on a black powder charge separating the airframe at the
right moment. Too little and the sections do not part; too much and you damage the
airframe or the parachute you are trying to deploy. The charge mass is not something you
can confidently calculate and walk away from. It gets massed out, fired, and watched.

Separation test in slow motion

*A later test on the finished, painted vehicle, filmed at 120fps and slowed roughly 3x.
The charge fires, the airframe splits at the coupler, and the two sections push apart
with the shock cord paying out between them. Slowing it down is what makes it useful:
you can see whether the sections separate cleanly and stay tethered, rather than just
hearing a bang.*

Separation charge ground test

*An earlier test on the bare airframe, real time. Fired remotely, triggered from a phone
over a wireless link to the firing board and out to the e-match. Full resolution clip:
[`separation-charge-test.mp4`](media/testing/separation-charge-test.mp4).*

Charge mass on a precision scale

*Massing a charge on a jeweller's scale during test preparation. The reading is 2.494 g.
This is the measurement step the section above is about: the charge mass is set on a
scale, not estimated.*

**What I did:** designed and ground-tested the separation charges, using an **Eggtimer
Quantum** as the firing system and **e-match** ignition, iterating charge mass until the
recovery system deployed reliably. I worked with the team leads to estimate the starting
charge requirement, and debugged power and electronics faults that came up during testing.

### Finding the charge mass by bisection

The charge mass was not guessed at and it was not swept linearly. The procedure written up
for the team, and the one I ran, is a **binary search on charge mass**:

1. Fire one test at **1 g** and one at **2 g** to bracket the answer immediately.
2. If both are too weak, jump the bracket up to 3 g and 4 g.
3. If 1 g is too weak and 2 g works or overshoots, the answer is inside 1 to 2 g, so test
   **1.5 g** next.
4. Keep halving the interval until the charge lands on a clean, forceful separation.
5. Once a charge gives a consistent result, fire it **2 to 3 more times** to confirm it is
   repeatable rather than lucky.

The target is the *minimum* charge that separates cleanly every time: enough that it never
merely pops open, not so much that it damages the airframe or the parachute. Bracketing
and halving converges in **3 to 4 tests**, where a linear sweep would burn far more
hardware and far more range time to reach the same answer.

This is the part of the project I find easiest to explain to software people. It is a
binary search, run against a physical system where every probe costs a rebuild, a drive to
a test site and a finite supply of e-matches. The cost per iteration is what makes the
choice of search strategy matter.

> **Evidence note, read this before quoting numbers.** The hardware, the firing method and
> the bisection procedure are documented in the
> [extract above](docs/fin-flutter-and-separation-testing-extract.pdf). What is *not*
> recorded anywhere is the per-test result table: this repository holds no test log, so I
> cannot say from the record alone which charge mass finally flew. The photograph above
> evidences one charge being massed at 2.494 g, which sits inside the 1 to 4 g range the
> procedure works through, but whether it was an intermediate probe or the final answer is
> my recollection rather than a record. I have deliberately not invented numbers to fill
> that gap.

---

## Launch

Launching a high-power vehicle out of Vancouver means driving it to a site that will take
it. For this campaign that was Pasco, Washington: 603 km and about six and a quarter
hours from the Hennings Building on campus, across the border.

<table>
<tr>
<td width="50%">Route from UBC to Pasco, Washington</td>
<td width="50%">With the vehicle at the launch site</td>
</tr>
<tr>
<td><em>The drive. UBC Hennings Building to Pasco, WA: 603 km, 6 hr 14 min, one border crossing.</em></td>
<td><em>With the Big Mach at the launch site.</em></td>
</tr>
</table>

The Big Mach at the launch site

*The finished vehicle at the launch site.*

At the launch site with the sub-team

*At the launch site with the sub-team. It was extremely windy, which is the kind of thing
that decides whether a launch window happens at all. Our team lead is not in any of the
photos, only in the video from the same day:
[`launch-site-team-video.mp4`](media/launch/launch-site-team-video.mp4).*

---

## What I took away from it

**Ground testing energetics is not optional.** The charge mass that "should" work and the
charge mass that reliably separates a specific airframe, with a specific shear pin and
seal arrangement, are different numbers. There is no honest way to close that gap except
to mass a charge out on a scale, fire it, and watch what the airframe actually does. That
is why there is a photo of a jeweller's scale in this repository: the number came off an
instrument, not out of a formula, and it took more than one attempt to find it.

**Composite processes have tolerances that CAD does not.** The layup diameter mismatch
cost a full rework because we treated the layup as a way to realise a drawing rather than
as a process with its own variation. A mandrel sets a starting diameter. Layer count,
resin uptake and compaction set the finished one, and a coupler fit toleranced tightly on
paper has almost no room to absorb the difference. I now design a layup against a target
finished inside diameter and verify it, instead of inferring it from the tooling.

**Integration is a design constraint, not a final step.** The avionics bay had to be
serviceable by people who were not me, working on hardware I did not design and would not
be there to explain. That requirement changed the geometry: access, fastener choice and
routing all got decided by someone else's workflow rather than by what was easiest to
model. Designing for another team's hands is a different problem from designing for your
own.

**Most of the job was translation.** I came in expecting the work to be CAD. What it
actually was, most weeks, was taking a constraint from recovery, avionics, embedded
software or composites, understanding enough of that sub-team's problem to know which
parts of the constraint were real and which were preference, and turning the result into
geometry someone could print or lay up. The vehicle was the easy part to draw. Knowing
what it had to be was the work.

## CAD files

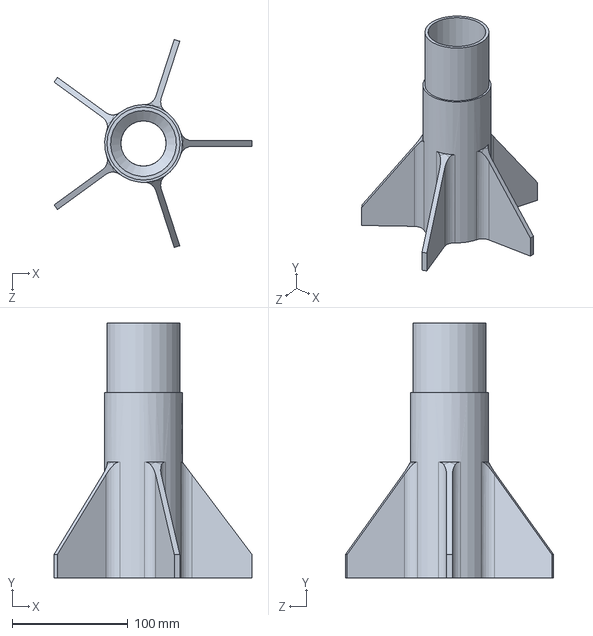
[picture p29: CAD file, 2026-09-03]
star-raptor/cad/MyRocketAssemFinal.SLDASM
170.7 x 220.0 x 179.5 mm

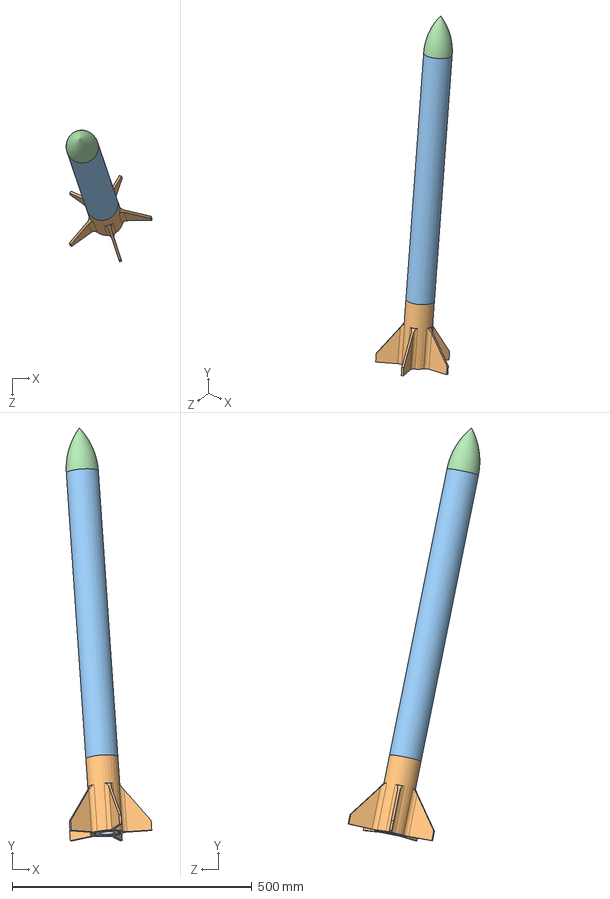
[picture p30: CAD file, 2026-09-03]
star-raptor/cad/MyRocketAssem.SLDASM
178.6 x 860.9 x 274.5 mm
nosecone
LowerBodyTube
FinCan
endcap

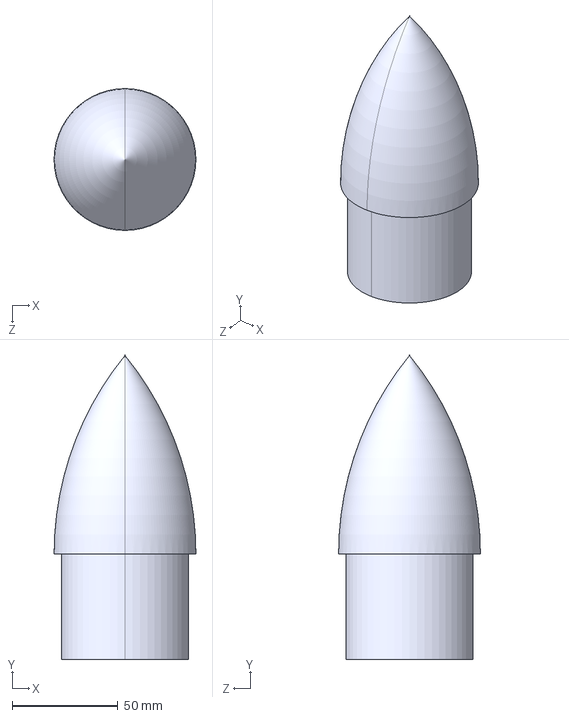
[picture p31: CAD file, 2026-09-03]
star-raptor/cad/final print top parts/nosecone.STEP
67.1 x 143.9 x 67.1 mm

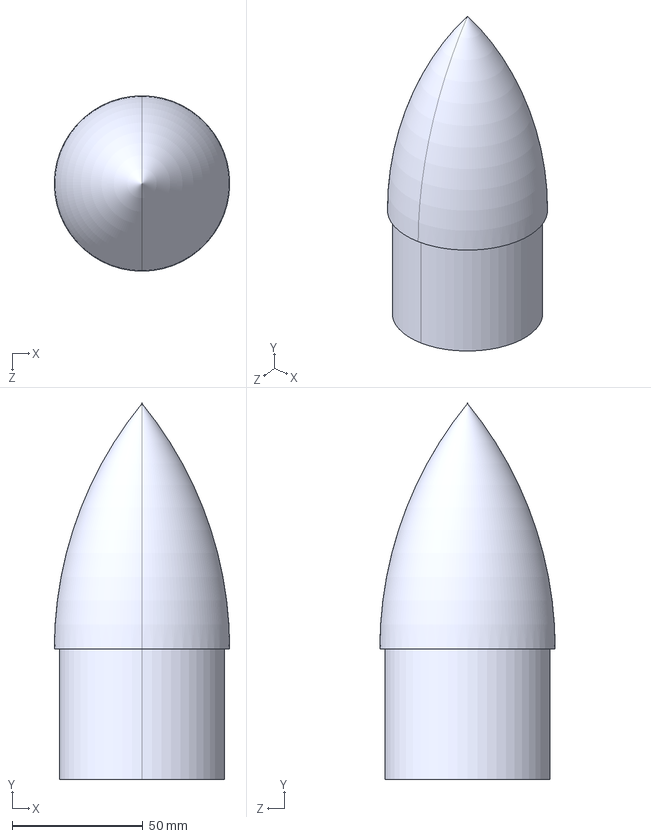
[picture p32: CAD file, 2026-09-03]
star-raptor/cad/toprint/nosecone 631mm.STEP
67.1 x 143.9 x 67.1 mm

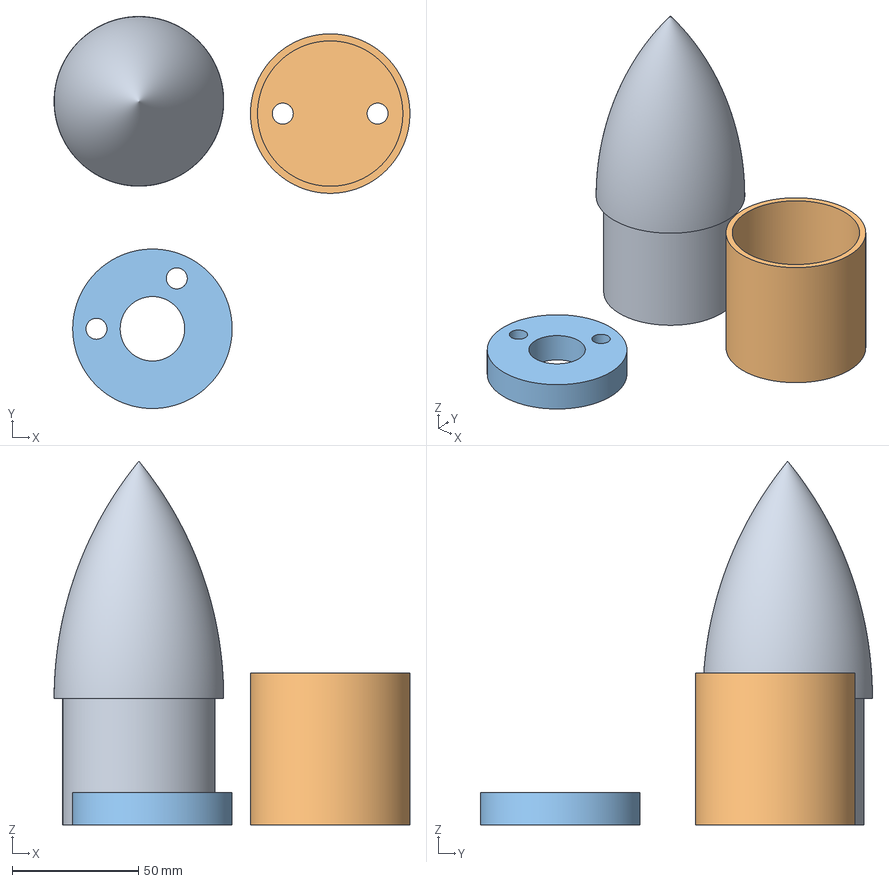
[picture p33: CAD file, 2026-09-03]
star-raptor/cad/final print top parts/projectfilefortopparts.3mf
140.8 x 155.1 x 143.9 mm
nosecone.STEP
Uboltattatchmentpartnosecone.SLDPRT.STEP
uboltattatchmentpartBT.STEP

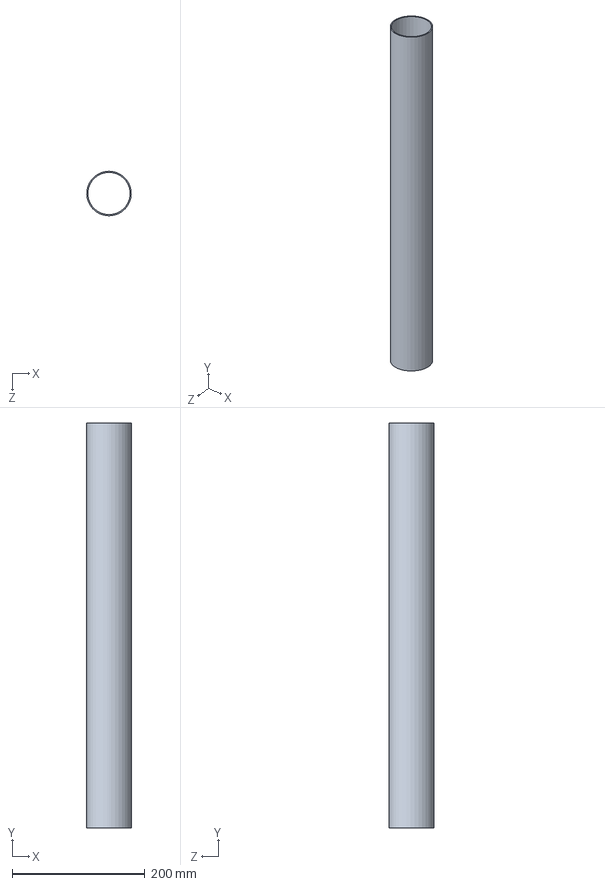
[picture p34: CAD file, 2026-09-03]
star-raptor/cad/LowerBodyTube.SLDPRT
67.1 x 609.6 x 67.1 mm

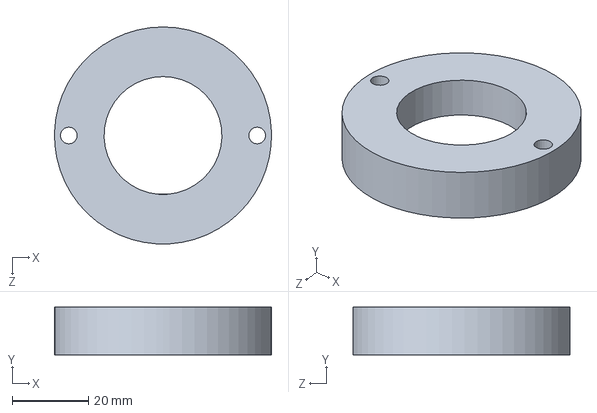
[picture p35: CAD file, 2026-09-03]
star-raptor/cad/endcap.SLDPRT
57.1 x 12.6 x 57.1 mm

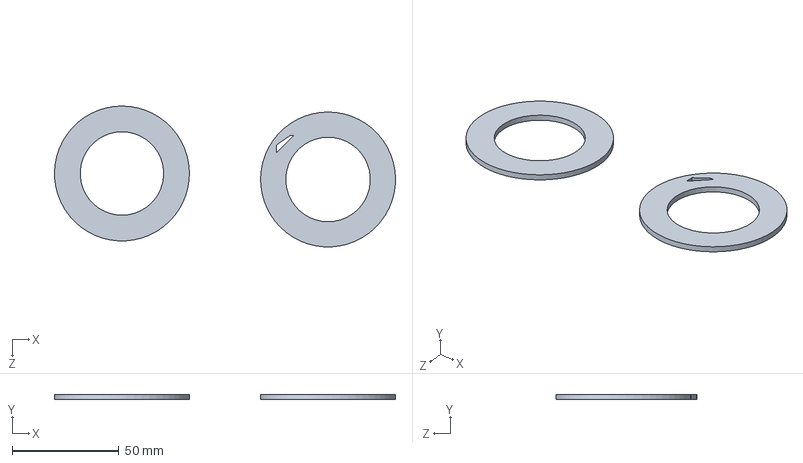
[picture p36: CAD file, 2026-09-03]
star-raptor/cad/toprint/micropart.SLDPRT
159.4 x 2.50 x 65.9 mm

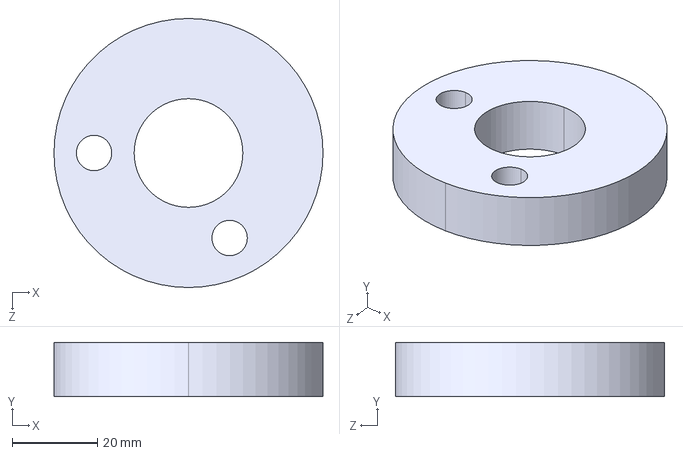
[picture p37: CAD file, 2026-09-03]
star-raptor/cad/final print top parts/uboltattatchmentpartBT.STEP
63.1 x 12.7 x 63.1 mm

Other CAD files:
star-raptor/cad/FinCan.SLDPRT
star-raptor/cad/toprint/fincap end cap final final.gcode.3mf
star-raptor/cad/toprint/finalfinalFinCan.STEP
star-raptor/cad/nosecone.SLDPRT
star-raptor/cad/toprint/FinCan.STEP
star-raptor/cad/final print top parts/myparts.gcode.3mf
star-raptor/cad/toprint/Fincan+Endcap.gcode.3mf
star-raptor/cad/toprint/endcap.STEP
star-raptor/cad/toprint/microprints.STEP
star-raptor/cad/Uboltattatchmentpartnosecone.SLDPRT
star-raptor/cad/final print top parts/Uboltattatchmentpartnosecone.SLDPRT
star-raptor/cad/final print top parts/Uboltattatchmentpartnosecone.SLDPRT.STEP
star-raptor/cad/toprint/FinCan.3mf
star-raptor/cad/toprint/Uboltattatchmentpartnosecone.STEP
star-raptor/cad/toprint/microprints.3mf
star-raptor/cad/toprint/uboltattatchmentpart.STEP
star-raptor/cad/toprint/uboltnoseconepart.3mf
star-raptor/cad/toprint/uboltnoseconepart.STEP
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

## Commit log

2026-09-02 docs: add Big Mach and Star Raptor engineering documentation
    Build out the repository from an empty scaffold into a documented
    portfolio of my UBC Rocket work.
    - Root README: what each project is, what I personally did, and how the
    two differ in scope and team structure.
    - big-mach/: vehicle purpose as a test article for the reefing parachute
    and in-house avionics; verified OpenRocket parameters (146 cm, 7.7 kg
    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
2026-09-03 docs: add converted media, launch section, and CAD release link
    Convert the remaining HEIC/MOV source files and fold them into the
    project READMEs alongside the content they explain.
    New media:
    - separation-charge-test.gif: the 10s ground test trimmed to the 3.4s
    around the event, 480x270. GitHub does not preview mp4 inline, so the
    strongest piece of evidence in the repo was previously download-only.
    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
2026-09-03 docs: drop evidence index tables, expand engineering takeaways
    The evidence tables were doing bookkeeping rather than saying anything.
    Remove both and put the weight into "What I took away from it", which is
    the section that actually shows engineering judgement.
    Big Mach takeaways expanded to four, adding the cross-sub-team
    translation work that was most of the job week to week. Star Raptor
    expanded to four, adding scoping as the real engineering content.
    The inline evidence notes on the layup rework and the separation charge
    campaign are kept: those mark specific claims as memory rather than
    record, and removing them would overstate what the repo backs up.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
2026-09-03 docs: add fin flutter analysis, slow-motion separation test, avionics wiring
    Fin flutter is the largest addition. The repo previously showed no
    quantitative aero work at all, and this is the strongest engineering
    content available: NACA TN 4197 Eq. 18 evaluated along the OpenRocket
    trajectory, with the fin geometry from the CAD model, giving flutter at
    Mach 2.5-2.9 against a vehicle peaking just under Mach 1.0. The weak
    input (assumed shear modulus) is called out rather than hidden, along
    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
2026-09-03 docs: add testing documentation extract and bisection method writeup
    Publish the team testing documentation as a 7-page extract rather than
    in full. Kept: the fin flutter derivation and working (pages 1-5) and
    the charge-search experiment (page 12). Dropped: the operational wifi
    pages carrying hardware credentials, and the black powder packing
    procedure, which is credited to another sub-team and contains
    photographs of a third party from an external tutorial.
    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
2026-09-03 docs: state the testing document as collaborative, scope the claim to fin flutter
    Jeremy contributed to the document but cannot attribute specific
    sections beyond the fin flutter analysis. Say that plainly rather than
    implying sole authorship: name fin flutter as his own work, acknowledge
    the wider contribution without drawing a false line around it, and keep
    the bisection procedure framed as a team writeup that he executed.
    Claude-Session: https://claude.ai/code/session_01NZRLZca5Q1tbkVjzFnLqks
2026-09-03 docs: embed flutter figures inline, correct launch photo caption
    GitHub cannot embed a PDF inside a README (img will not render one and
    embed/iframe are stripped by the HTML sanitizer), so the flutter plots
    were only reachable by clicking away from the page. Extract the four
    figures as PNGs and place them beside the text they support:
    - the NACA TN 4197 equation, next to the method description
    - the OpenRocket fin set dialog, next to the geometry table
    - flutter velocity vs altitude, and vs vehicle velocity, at the result
    The vs-vehicle-velocity plot is the one that carries the argument: two
    curves that never touch is the entire conclusion, and it now renders on
    the page instead of being b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
2026-09-03 docs: add Star Raptor CAD source, renders, and print preparation
    Adds the SolidWorks source for Star Raptor (parts, assemblies, STEP
    exports and sliced print files, 19 MB) under star-raptor/cad/, plus
    seven CAD renders cropped out of the SolidWorks UI and two build plate
    previews pulled from the sliced project files.
    Star Raptor README gains a Design section (full assembly, exploded view,
    section views, component table) and a "From CAD to printed part"
    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
    [FinCan.3mf, FinCan.SLDPRT, FinCan.STEP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]
2026-09-04 docs: correct PA6GF rationale, note five-fin choice, remove flight claim
    The Big Mach nose cone was printed in PA6GF rather than PA6CF because
    glass-filled nylon passes radio waves and carbon-filled nylon does not;
    the cone sits over the avionics. The README had attributed the choice to
    aerodynamic heating alone.
    Record that Star Raptor's five-fin can was a cosmetic choice the
    stability margin accommodated rather than a design requirement, flagged
    as memory since no stability model for the vehicle is in the repository.
    Star Raptor's certification launch was scrubbed by weather and the
    vehicle has not flown. Removed the claims that it did.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
